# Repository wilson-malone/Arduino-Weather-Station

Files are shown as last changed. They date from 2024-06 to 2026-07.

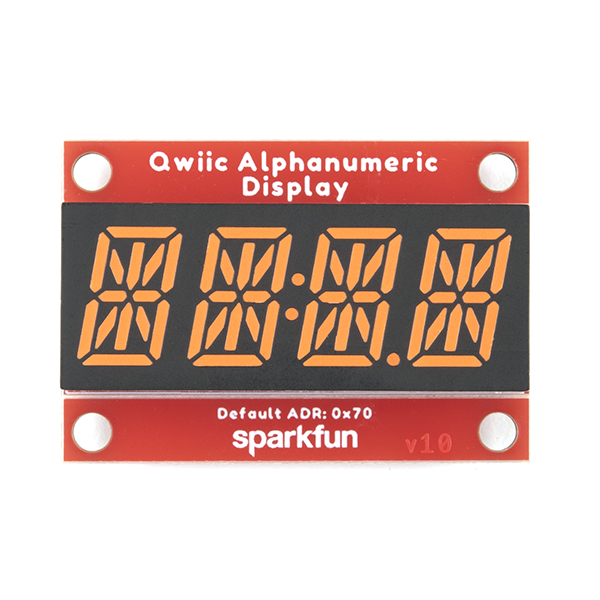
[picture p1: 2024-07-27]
Schematics/14 segment display/16919-SparkFun_Qwiic_Alphanumeric_Display_-_Pink-03a.jpg

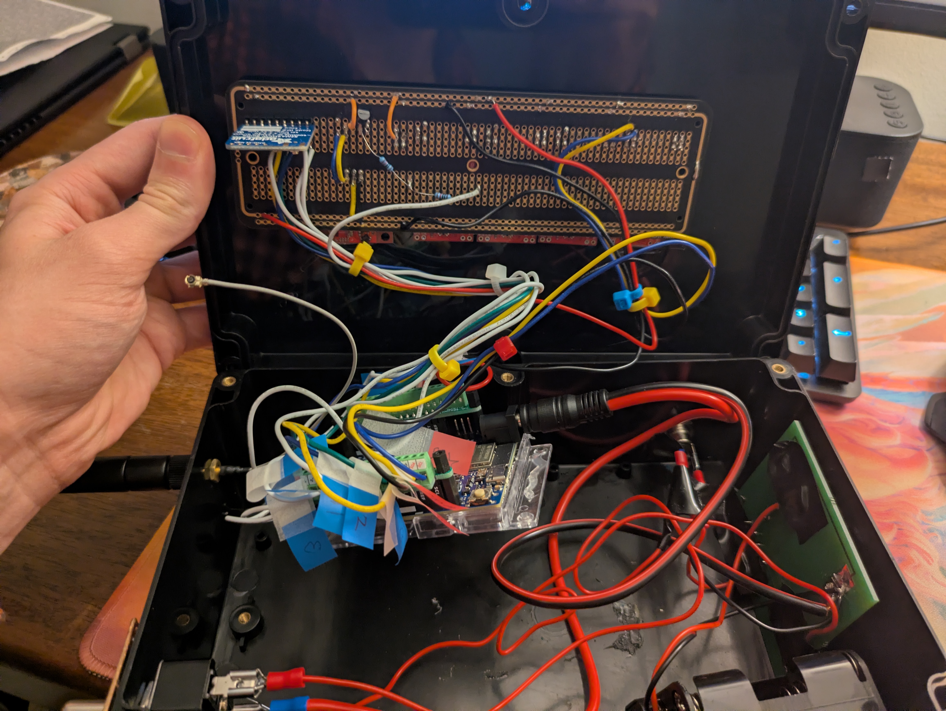
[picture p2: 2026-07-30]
Pictures/PXL_20260730_175343006[1].jpg

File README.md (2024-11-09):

# WeatherStation
Home Made Arduino Weather Station
Weather Measurement and Wireless Reporting Device

Custom Libraries Needed:

Wind Functions: https://github.com/wilson-malone/RS485_Wind_Direction_Speed_Sensors_Arduino: Avaialable through the Arduino IDE library manager.
s7s: A quick and light library to use the 7 segment displays. Download it here.

Objective: To provide a means of measuring the parameters of atmospheric temperature, humidity, pressure, wind direction, and wind speed. The parameters are then to be transmitted wirelessly to a receiver and display unit.

Introduction

Weather data obtained online often does not have the localized detail or time resolution that is useful for accurate measurement. 

Power considerations: 

The transmitter and sensors have been measured by a multimeter to use an average of 90mA over time. The transmitter spikes to 150mA during transmissions, however the average remains lower. The shortest day-length in the intended region is 8 hours, constituting 1/3 of the 24 hour cycle. The solar panel average output must therefore be at least 300mA over the course of a day to run the transmitter and charge the battery sufficiently. Solar panels rated at 1A will be preferred to account for inefficiencies resulting from cloud cover and obstacles. The battery will be 12 volts lead acid, chosen for its stable chemistry and suitability to deep discharging. To run through the night, the transmitter will use 1.44Ah of energy. Running a battery at or near its capacity is undesirable and reduces battery life, therefore, a battery with a significantly larger capacity will be used.

The reciever and components have a measured power consumption of 110mA.

Components

The anemometer and wind direction sensor use RS485 serial communication limited at 9600baud. The transmitter uses a daughter board designed to interface with the microcontroller’s hardware serial system and convert to the necessary protocol. The rate of sensor readings is limited by the speed of this communication style to once every 3 seconds. These two sensors require 7-24 volts to operate, and consume 15mA each. This power will be provided by a direct connection to the solar charge controller.

The receiver uses four 7-segment displays for displaying temperature, pressure, humidity, and wind speed. A 14 segment alphanumeric display is used to display wind direction as one of the 16 cardinal directions. The displays are serial type displays, utilizing the I2C protocol. This was chosen for the few number of wires required to communicate with these displays. Only two wires, SDA, and SCL are required to communicate with all five displays which are wired in parallel. Each display can be programmed with a unique two-digit hexadecimal address. When transmitting a command to the display, the address is called out, along with the command.

The temperature, pressure and humidity (PHT) sensor sensor utilizes I2C communication, chosen for the relatively few wires that it requires. It operates at 3.3v DC, and will be powered using the Arduino 3.3v pin.

The radio transceivers use SPI communication. They operate in the range of 868 to 915 MHZ, corresponding to the American ISM band that does not requires a license at this power level. 

Microcontrollers

The microcontrollers will be Arduino units, chosen for their built-in power regulation and widespread compatibility with many types of hardware.

An Uno3 utilizing will be used for the server unit (sensor unit), and an Uno 4 WIFI will be used for the client (display unit).

Networking

The two units will communicate over 915mhz utilizing frequency shift key modulation. The data will be sent as a data structure consisting of 16 bit signed integers for each of the sensor parameters. These are stored internally as little endian, so the byte order will be changed to MSB big endian for transmission, and re-converted on reception. The transmission protocol is Manchester encoding to prevent DC bias, and to ensure readability for SDR receivers. Since this is a weather station, making the transmission maximally readable to other types of radios is the priority. The client unit will also have Wi-Fi connectivity, and connects to Arduino cloud to transmit the weather data. This is conencted to the smartphone app which can display the parameters.

Error reporting

Both units have basic error reporting. The server unit can give sensor fail warnings by transmitting specific numbers in place of sensor readings. The PHT sensor functions can determine if the unit is not responding, and will display the number ‘8’ in place of its sensor readings. If the wind direction sensor is not responding within 1000ms, the function will return an ‘18’ which displays as “FAIL’ on the alphanumeric display. If the anemometer does not respond in 1000ms, the function returns a ‘-1.’ The client unit displays ‘INIT’ when it sends a request to the server on first startup. The client unit has a function where it informs of the absence of a returned signal. The client counts the number of milliseconds between radio transmissions. If the gap between transmissions exceeds 5 seconds, the alphanumeric display will show ‘NO SIGNAL’ in scrolling text, and the other displays will turn off. A blinking  LED light on both transceivers will inform when a transmission has been received. The server unit has a power conserving standby mode, where if it has not received a request in 8 seconds, the radio will listen continuously for incoming packets. The outgoing data structure will be set to ‘7’ in all the categories, and the wind direction will send 19, although this is more for internal use, and it won't be transmitted.

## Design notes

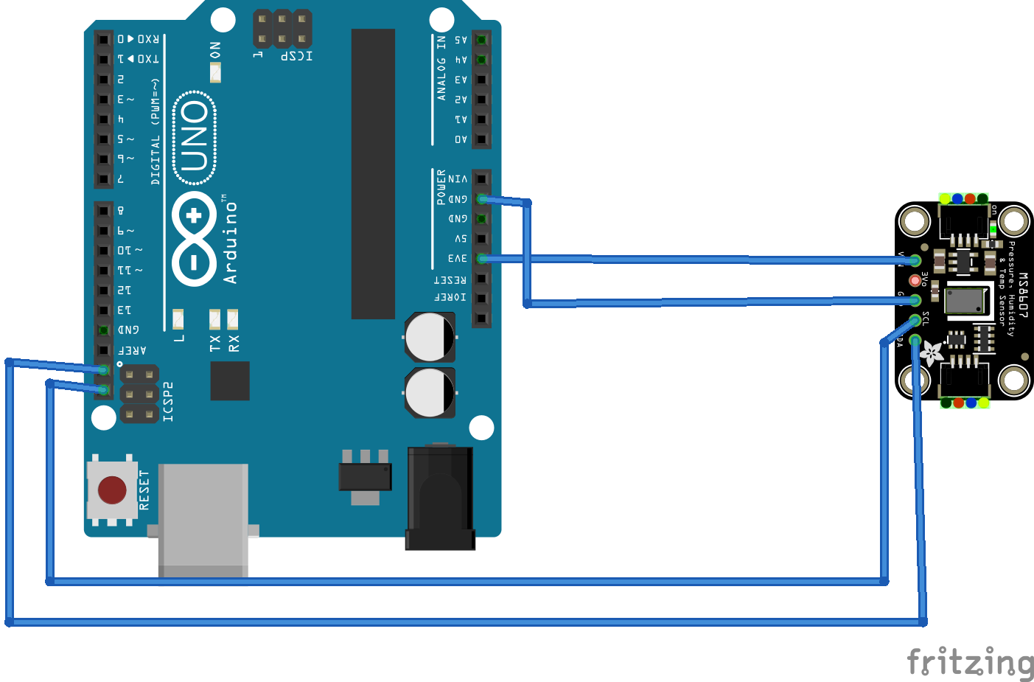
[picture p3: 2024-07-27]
Schematics/PHT Sensor/PHT Sensor_bb.png

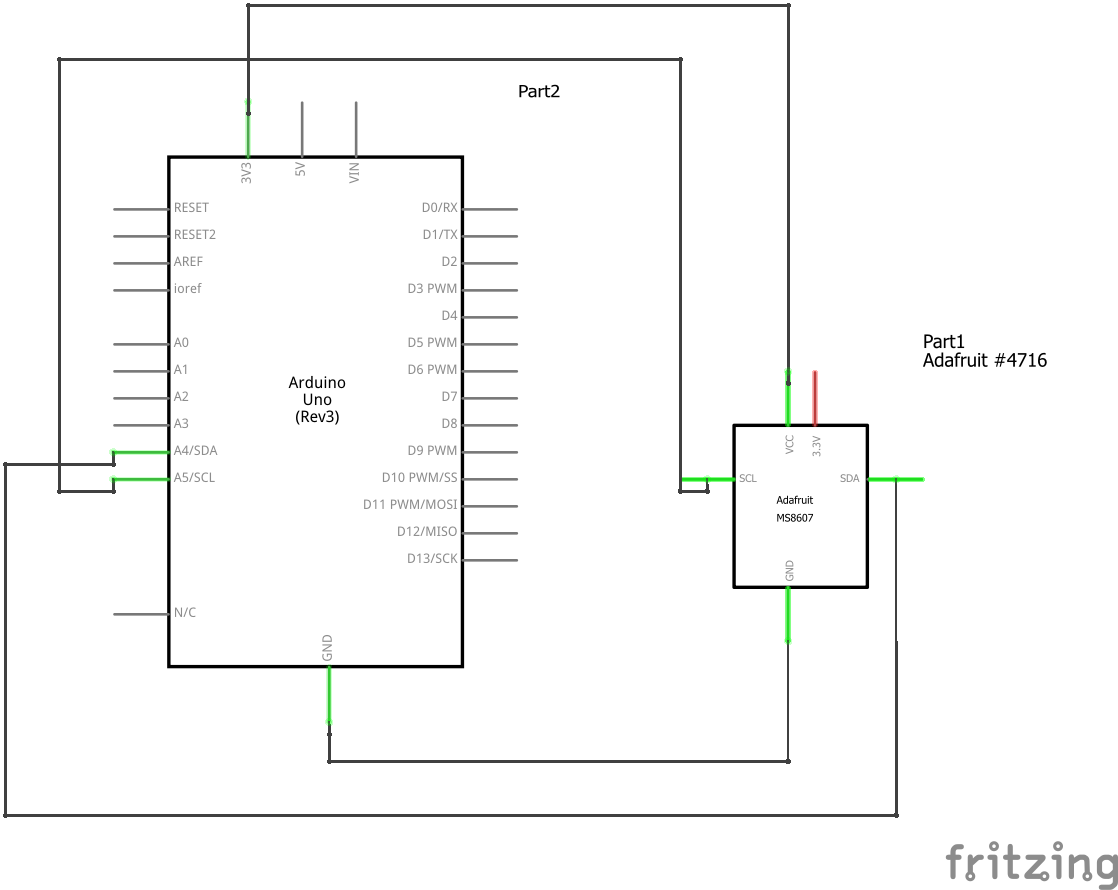
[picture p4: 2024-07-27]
Schematics/PHT Sensor/PHT Sensor_schem.png

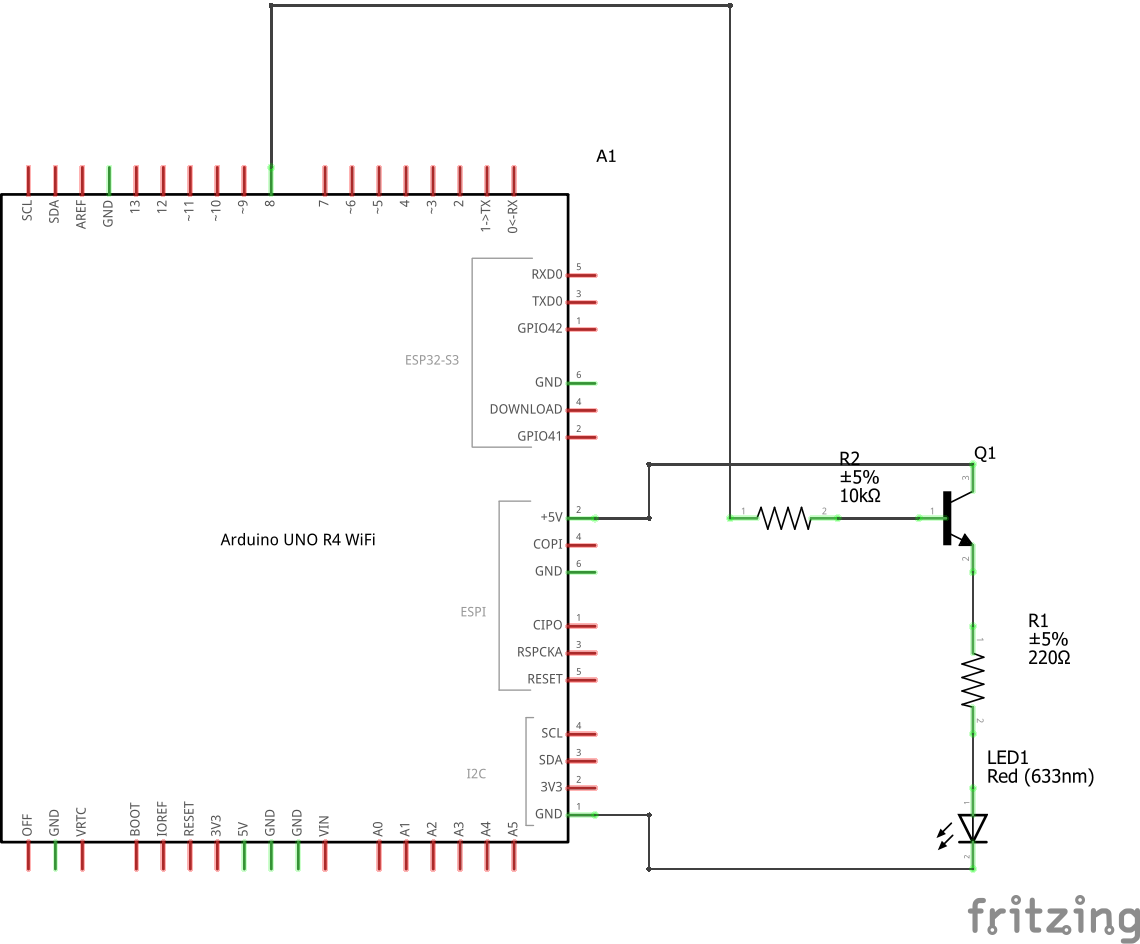
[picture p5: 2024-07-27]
Schematics/Blinking LED/Transistor_schem.png

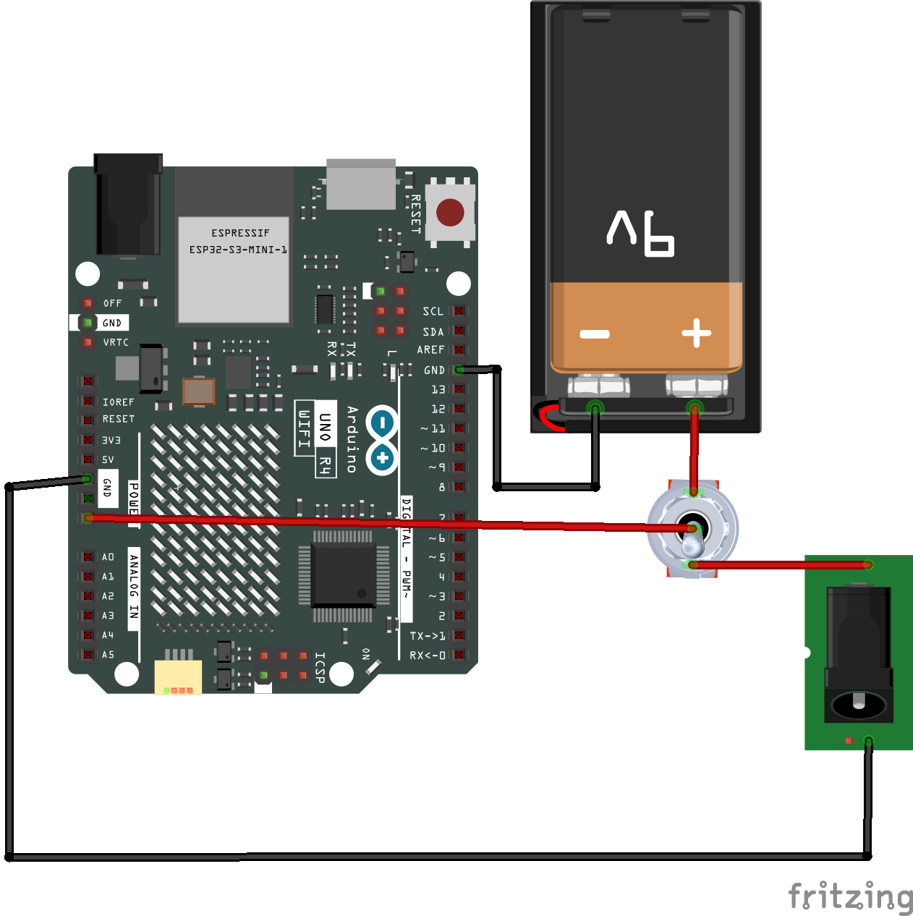
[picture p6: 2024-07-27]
Schematics/Power client/client power_bb.png

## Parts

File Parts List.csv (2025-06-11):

Adafruit MS8607 Pressure Humidity Temperature PHT Sensor - STEMMA QT / Qwiic | https://www.adafruit.com/product/4716#technical-details | 1 | $14.95
Adafruit RFM69HCW Transceiver Radio Breakout - 868 or 915 MHz - RadioFruit | https://www.adafruit.com/product/3070 | 2 | $9.95
RS485 Wind Vane Direction Sensor | https://www.dfrobot.com/product-2340.html | 1 | $45.00
RS485 Wind Speed Transmitter (0~32.4m/s) | https://www.dfrobot.com/product-2339.html | 1 | $45.00
RS485 Shield for Arduino | https://www.dfrobot.com/product-1024.html | 1 | $9.90
SparkFun 7-Segment Serial Display - Blue | https://www.sparkfun.com/products/11442 | 4 | $14.95
SparkFun Qwiic Alphanumeric Display - Red | https://www.sparkfun.com/products/16916 | 1 | $9.95
Arduino UNO R4 WIFI | https://store-usa.arduino.cc/products/uno-r4-wifi?selectedStore=us | 1 | $27.50
Arduino Uno Rev3 | https://store-usa.arduino.cc/collections/boards-modules/products/arduino-uno-rev3?_pos=4&_fid=10a13d619&_ss=c
Solar Panel 1A max rating | https://www.amazon.com/TP-solar-Monocrystalline-Controller-Extension-Terminal/dp/B07RZBVTGR | 1 | $29.99
Battery Lead Acid 9Ah | https://www.amazon.com/gp/product/B00A82A3QG/ref=ppx_od_dt_b_asin_title_s01?ie=UTF8&psc=1 |  | $23.50
Project Boards | https://www.amazon.com/gp/product/B0BX8M1RKR/ref=ppx_od_dt_b_asin_title_s01?ie=UTF8&psc=1 | 1 | $17.99
Project Box | https://www.amazon.com/gp/product/B0B5QGM83Y/ref=ppx_od_dt_b_asin_title_s02?ie=UTF8&psc=1 |  | $15.59
Arduino Headers | https://www.amazon.com/gp/product/B08XWCN43C/ref=ppx_od_dt_b_asin_title_s01?ie=UTF8&psc=1 | 1 | $18.90
16mm Waterproof Connector 2 pin | https://https://www.amazon.com/dp/B0816BRS6N | 1 | $12.59
16mm Waterproof Connector 4 pin | https://www.amazon.com/dp/B08169TKZH | 2 | $13.49
22 AWG wire | Various
Waterproof Box | https://www.amazon.com/gp/product/B0BWK5LXTR/ref=ppx_od_dt_b_asin_title_s00?ie=UTF8&psc=1 | 1 | $54.99
9V Battery Pack | https://www.amazon.com/dp/B0768P78P1?psc=1&ref=ppx_yo2ov_dt_b_product_details | 1
uFL to SMA cable |  | 2
915 MHZ antenna |  | 2
DC Power Socket 5.5x2.1 |  | 1
DPST Switch |  | 1
SPDT Switch |  | 1
P2N2222A NPN Transistor |  | 1
5mm LED |  | 2
uFL SMT Antenna Connector | https://www.adafruit.com/product/1661 | 2 | $0.75
9v center positive 5.5x2.1 power adapter |  | 1
Right angle Breakaway Headers | https://www.adafruit.com/product/1540 | 1 | $5.95
Straight Breakaway Headers | https://www.adafruit.com/product/3009 | 1 | $4.95
220 ohm 1/4 watt resistor | various | 2
6.3mm female spade connectors | various | 10
Schottkey Diodes 1N5819 A0G | Mouser | 2 | $0.26
MOSFET 78-IRF9610PBF-BE3 | Mouser | 2 | $1.07
MOSFET 698-VN2106N3-G | Mouser | 1 | $0.50

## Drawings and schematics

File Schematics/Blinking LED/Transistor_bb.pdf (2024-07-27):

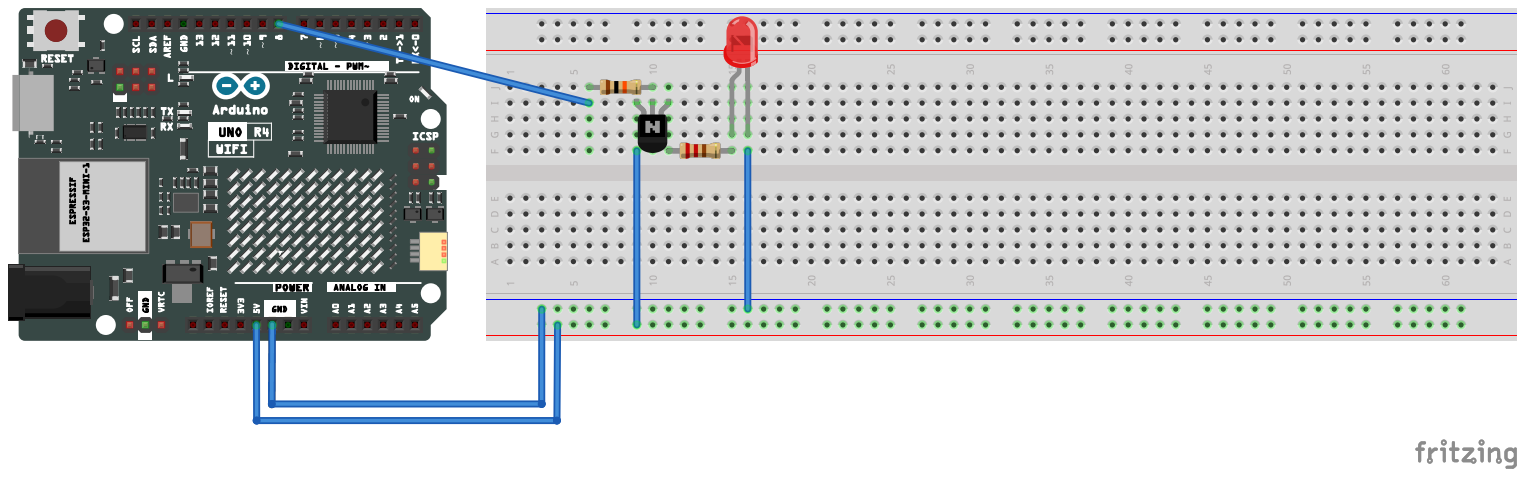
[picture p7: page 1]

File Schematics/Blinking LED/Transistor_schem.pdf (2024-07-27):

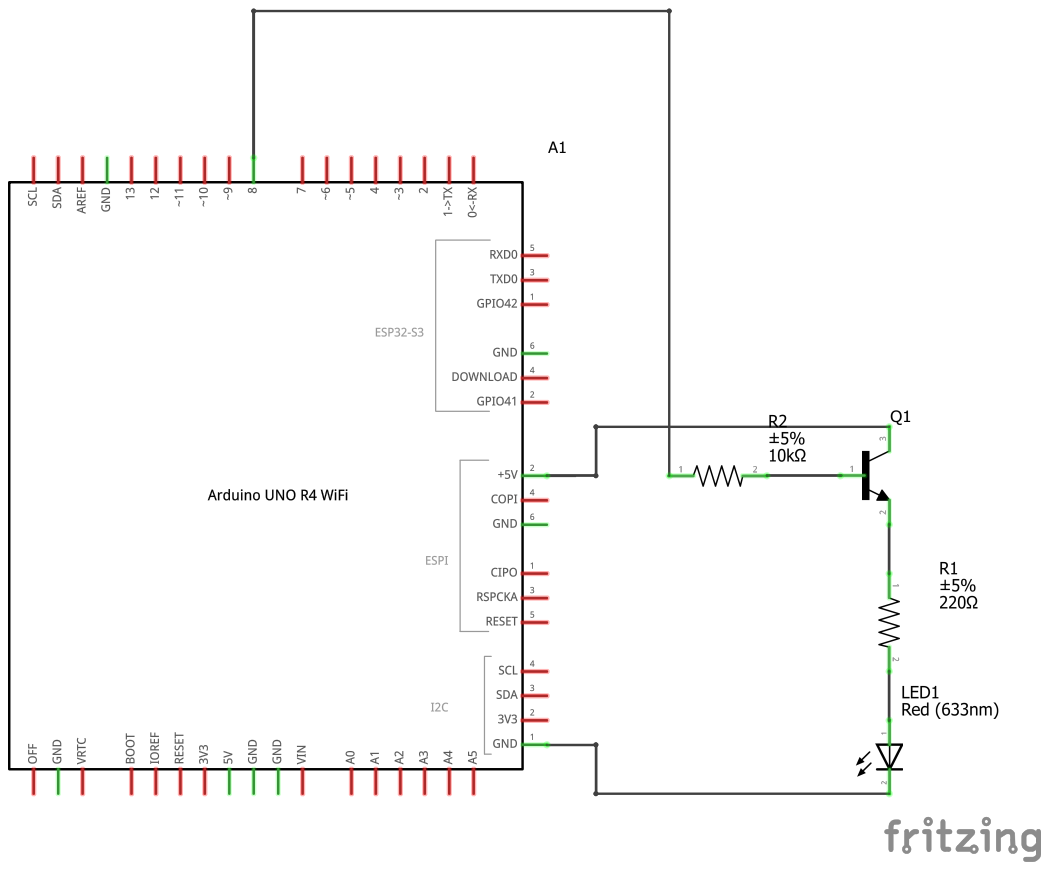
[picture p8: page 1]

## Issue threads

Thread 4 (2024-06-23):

Add transistor control to the wind sensors.

wilson-malone, 2024-06-23:
The server has a standby mode, but currently the wind sensors remain on and consume about 30mA combined. Add transistors to control the power to them define a digital pin in the code to turn them on and off.

wilson-malone, 2024-10-18:
Solved, see schematics. Added transistor and coded logic to control the sensors.

Closed 2024-10-18.

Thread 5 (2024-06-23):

Add automatic battery power to the client unit so that power doesn't have to be switched off to go between AC and battery power.

wilson-malone, 2024-06-23:

wilson-malone, 2024-10-18:
Solved. See schematics for PCB design.

Closed 2024-10-18.

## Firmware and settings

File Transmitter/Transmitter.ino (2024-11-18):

#include <Wire.h>             // I2C library
#include <Adafruit_MS8607.h>  // Adafruit
#include <Adafruit_Sensor.h>  //Adafruit
#include <RH_RF69.h>          //Radiohead library
#include <SPI.h>              // Used for radio
#include <WindFunctions.h>    //Wind sensors: anemometer and wind direction vane
#include <RHDatagram.h>
#include <avr/sleep.h>
#include <avr/interrupt.h>

// Configuration
#define SERVER_ADDRESS 1 //This device's radio address
#define POWER 6 // Radio Power Output dbm
#define RF69_FREQ 902.3 // Radio Frequency
#define RFM69_CS 4   // Chip Select
#define RFM69_INT 3  // Interrupt
#define RFM69_RST 2  // Reset
#define LED 8        // Receiver LED pin
#define WINDSENSORS 5 //Pin that switches the wind sensors on or off for power saving
#define AZIMUTH 220 // The direction that the wind direction sensor is actually pointed.
#define ALT_CORRECTION 7 // InHG*100 correction for altitude


// Library Objects
Adafruit_MS8607 ms8607;       //creating object for the adafruit TPH sensor
WindFunctions wind_functions; //My library for the wind sensors :-)
RH_RF69 rf69(RFM69_CS, RFM69_INT);  //Create the object for the radio driver
RHDatagram rf69_manager(rf69, SERVER_ADDRESS); // Rediable datagram object for the radio


// Defining variables
unsigned long current_time;
unsigned long blink_interval;
bool blink;
bool LEDstatus;
bool messageRX;
bool standby;
uint8_t from;

//Structure defining the data from the sensors This structure used globally, so it's not in a class.
struct TPHData {
  int16_t temperature;
  int16_t pressure;
  int16_t humidity;
  int16_t speed;
  int16_t direction;
}; TPHData Bundle;  //Create the object for the data structure

#define CONFIG_GFSK (RH_RF69_DATAMODUL_DATAMODE_PACKET | RH_RF69_DATAMODUL_MODULATIONTYPE_FSK | RH_RF69_DATAMODUL_MODULATIONSHAPING_FSK_BT1_0)
#define CONFIG_MANCHESTER (RH_RF69_PACKETCONFIG1_PACKETFORMAT_VARIABLE | RH_RF69_PACKETCONFIG1_DCFREE_MANCHESTER | RH_RF69_PACKETCONFIG1_CRC_ON | RH_RF69_PACKETCONFIG1_ADDRESSFILTERING_NONE)

static const RH_RF69::ModemConfig Table = { CONFIG_GFSK, 0x01, 0x00, 0x08, 0x00, 0xe1, 0xe1, CONFIG_MANCHESTER};


void EndianChanger(){
  Bundle.temperature = htons(Bundle.temperature);
  Bundle.pressure = htons(Bundle.pressure);
  Bundle.humidity = htons(Bundle.humidity);
  Bundle.speed = htons(Bundle.speed);
  Bundle.direction = htons(Bundle.direction);
}
void RadioRX() {
  uint8_t buf[RH_RF69_MAX_MESSAGE_LEN];
  uint8_t len = sizeof(buf);
  current_time=millis();
  // Wait for a message addressed to us from the client
  if (rf69_manager.recvfrom(buf, &len, &from)) {
    if(!LEDstatus){blink=true;}
    messageRX = true;
  }

}

void RadioTX(){
  // Send a reply back to the originator client
  rf69_manager.sendto((uint8_t*) &Bundle, sizeof(Bundle), from);
}

void GetTPHSensorReadings() {
  sensors_event_t temp, pressure, humidity;
  //gets the sensor readings from the TPH sensor
  if (!ms8607.reset()) {

    Bundle.temperature = 8;
    Bundle.pressure = 8;
    Bundle.humidity = 8;

    Serial.println("TPH sensor is not responding");


  } else {
    ms8607.getEvent(&pressure, &temp, &humidity);
    Bundle.temperature = temp.temperature * 1.8 + 32;  //Converts Celcius to Fahrenheit
    Bundle.pressure = (pressure.pressure * 2.953) + ALT_CORRECTION;       //Converts from hPa to inHG*100. Decimal will be added later on the receiver end
    Bundle.humidity = humidity.relative_humidity;
  }
}

void goToSleep() {
  set_sleep_mode(SLEEP_MODE_PWR_DOWN);
  sleep_enable();
  sei();
  sleep_cpu();
  //Resumes here after sleep interrupt from radio
  sleep_disable();
  standby = false;
  digitalWrite(WINDSENSORS, HIGH);
  delay(1000); //The wind sensors don't wake up very quickly, and will give garbage readings.
}

void wakeUp() {
  //Nothing needs to be done here.

}


void setup() {
  Serial.begin(9600);

  //wdt_enable(WDTO_8S);  // Enable the Watchdog at 8 seconds. Resets the board if there's a hangup somewhere.
  Serial.println("Watchdog enable");

  
  // disable ADC
  ADCSRA = 0;
  Serial.println("ADC turned off");

  attachInterrupt(digitalPinToInterrupt(RFM69_INT), wakeUp, RISING);

  // Try to initialize adafruit sensor
  if (!ms8607.begin()) {
    Serial.println("Failed to find MS8607 chip");
  } else {
    Serial.println("Found MS8607");
  }

  //End of adafruit sensor module initialization

  //The Wind Sensors On-Off switch. Helps conserve power.
  pinMode(WINDSENSORS, OUTPUT);
  digitalWrite(WINDSENSORS, HIGH);

  //Radio Section
  pinMode(RFM69_RST, OUTPUT);
  pinMode(LED, OUTPUT);
  digitalWrite(RFM69_RST, LOW);

  Serial.println("RFM69 Start");

  digitalWrite(RFM69_RST, HIGH);
  delay(10);
  digitalWrite(RFM69_RST, LOW);
  delay(10);

  Serial.println("Radio Reset");

  if (!rf69_manager.init()) {
    Serial.println("Datagram manager initialization failed");
  } else {
    Serial.println("Radio Init OK");
  }

  if (!rf69.setFrequency(RF69_FREQ)) {
    Serial.println("setFrequency failed");
  } else {
    Serial.println("Frequency Set");
  }

  rf69.setModemRegisters(&Table);

  // If you are using a high power RF69 eg RFM69HW, you *must* set a Tx power with the
  // ishighpowermodule flag set like this:
  rf69.setTxPower(POWER, true);  // 2nd arg must be true for 69HCW
  Serial.print("Radio power set to"); Serial.println(POWER);
  Serial.print("RFM69 radio @"); Serial.print((int)RF69_FREQ); Serial.println(" MHz");

  //End radio section
}

void loop() {

  if (!rf69_manager.available()){
    if (!standby && millis()-current_time > 8000){
      digitalWrite(LED, LOW);
      digitalWrite(WINDSENSORS, LOW);
      rf69.setModeRx();
      messageRX = false;
      standby = true;
      goToSleep();
    }
  }else{
    RadioRX();
        //gets the TPH sensor readings
    GetTPHSensorReadings();
    //gets the direction sensor readings
    Bundle.direction=(wind_functions.readWindDirection360(0x02));
    
    if(Bundle.direction != -1){
      Bundle.direction = (Bundle.direction/10) + AZIMUTH;
      if(Bundle.direction == 0){
        Bundle.direction = 360;
      }
      if (Bundle.direction > 360){
        Bundle.direction = Bundle.direction - 360;
      }
    }
    //Gets speed sensor readings
    Bundle.speed = wind_functions.readWindSpeed(0x03) * 2.236;  // convert to miles per hour

    //Changes the byte order of outgoing 16 bit integers. 
    EndianChanger();
    RadioTX();
    }


  if(!blink && LEDstatus && millis()-blink_interval>30){
    digitalWrite(LED, LOW);
    LEDstatus=false;
  }

  if (blink && !LEDstatus){
    digitalWrite(LED, HIGH);
    blink=false;
    LEDstatus=true;
    blink_interval=millis();
  }

}

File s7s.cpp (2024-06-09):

#include <s7s.h>
#include <Arduino.h>
#include <Wire.h>


void s7s::Transmit(String toSend, byte decimals, byte address) {

	Wire.beginTransmission(address);
		for (int i = 0; i < 4; i++) {
		  Wire.write(toSend[i]);
		}
		Wire.endTransmission();

		setDecimals(decimals, address);

}

void s7s::setDecimals(byte decimals, byte address) {
	Wire.beginTransmission(address);
    Wire.write(0x77);
    Wire.write(decimals);
    Wire.endTransmission();
}

void s7s::clearDisplayI2C(byte address) {
    Wire.beginTransmission(address);
    Wire.write(0x76);  // Clear display command
    Wire.endTransmission();
}

void s7s::setBrightness(byte address, byte brightness) {
	Wire.beginTransmission(address);
	Wire.write(0x7A); // Brightness control command
	Wire.write(brightness); // Set brightness level: 0% to 100%
	Wire.endTransmission();


}

void s7s::addressChange(byte oldAddress, byte newAddress) {
	
	Wire.beginTransmission(oldAddress);
	Wire.write('v');
	Wire.endTransmission();

	//Send change address command
	Wire.beginTransmission(oldAddress); // transmit to device #1
	Wire.write(0x80); //Send TWI address change command
	Wire.write(newAddress); //New I2C address to use
	Wire.endTransmission(); //Stop I2C transmission

	Serial.println("I2C address changed to:"); Serial.print(newAddress);

	//Now we talk at this new address

	//Send the reset command to the display - this forces the cursor to return to the beginning of the display
	Wire.beginTransmission(newAddress);
	Wire.write('v');
	Wire.endTransmission();
	
}

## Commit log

2024-06-09 Add Client Receiver Code
    Arduino UNO R4
2024-06-09 Sensor Unit (Server)
2024-06-09 Wind Sensor Library
    RS485 anemometer and wind vane
2024-06-09 Wind Sensors
    RS485 anemometer and wind vane direction sensor
2024-06-09 Parts List
    Not xxhaustive and only includes electrical components, not structural or aesthetic.
    [Parts List.csv]
2024-06-09 Update Parts List.csv
    [Parts List.csv]
2024-07-27 Create Wiring_Diagrams
2025-01-29 Update Receiver.ino
    The WIFI update function caused a lot of stalling and hangups when WIFI is not connected. I made it so that the update is only called when new data has arrived.
